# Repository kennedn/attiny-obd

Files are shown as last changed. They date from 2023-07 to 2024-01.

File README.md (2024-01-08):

# attiny-obd

Display OBD statistics on a 16x2 LCD display using an attiny85.

This project hijacks the tx and rx serial lines on a conventional ELM327 OBD interface device to send and retreive data. This data is then displayed in a nice format on an LCD1602 via i2c.

<p align="center">
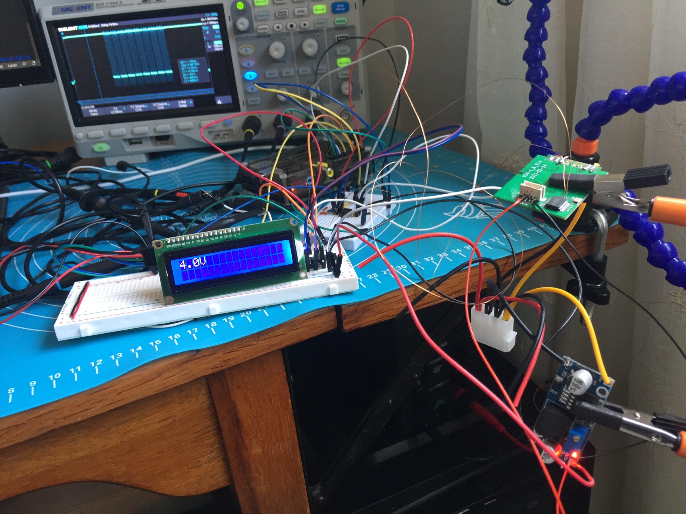
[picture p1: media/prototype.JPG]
    
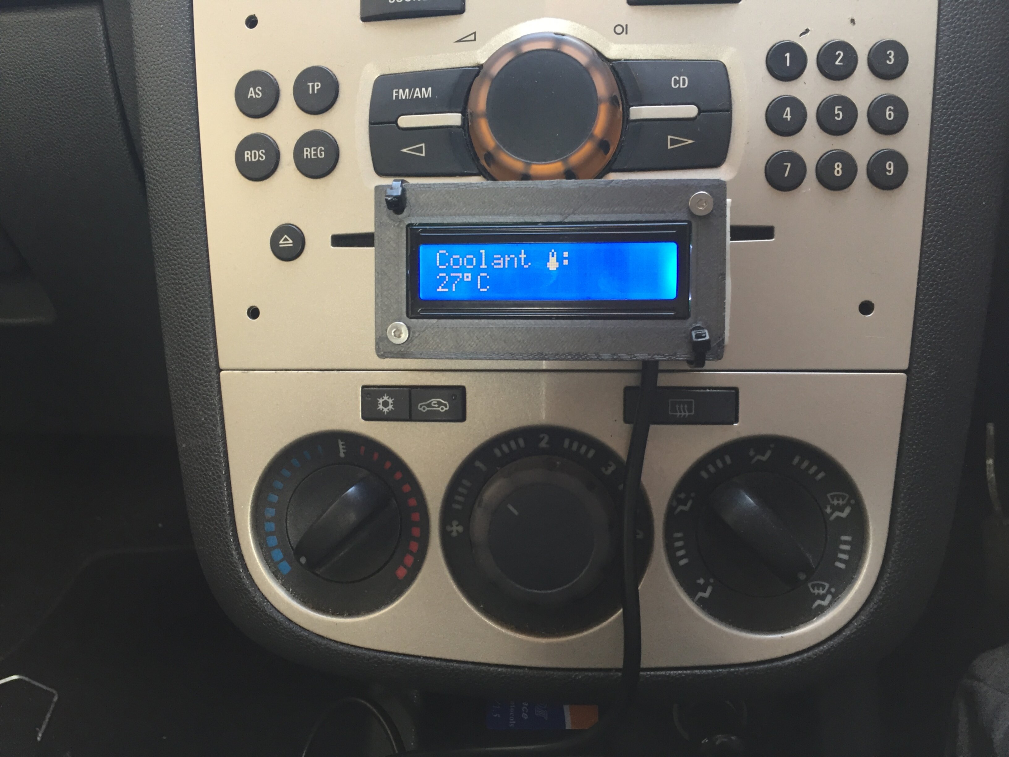
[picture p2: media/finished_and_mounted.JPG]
    
</p>
<p align="center">
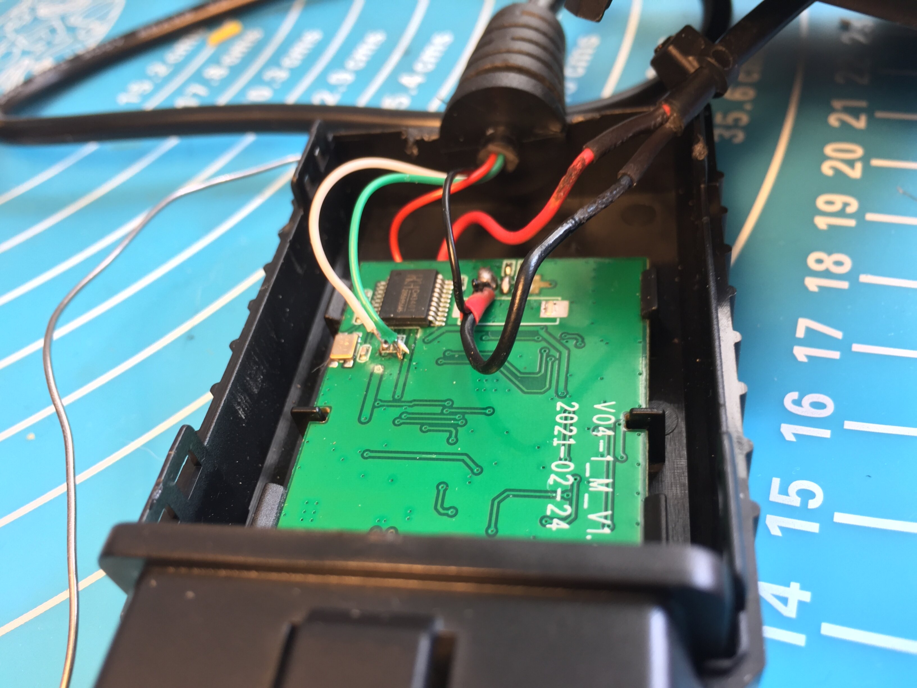
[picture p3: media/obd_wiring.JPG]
    
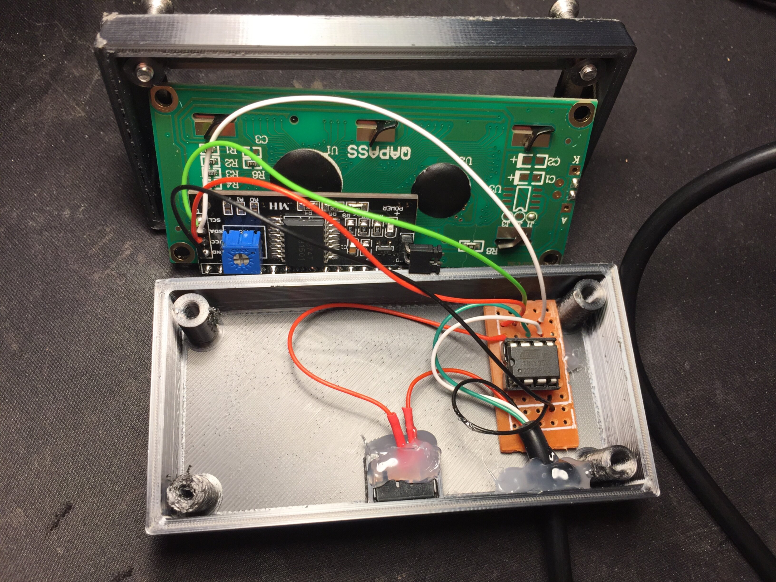
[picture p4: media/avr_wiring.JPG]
    
</p>

## Compiling and programming

An AVR programmer of choice can be used to program the attiny85, however a really easy way to achieve this is by using a spare raspberry pi as an SPI programmer. See the following blog post by Kevin Cuzner on how to set this up:

https://web.archive.org/web/20220629132626/http://kevincuzner.com/2013/05/27/raspberry-pi-as-an-avr-programmer/

Assuming that the linuxspi programmer is being used on a raspberry pi, the steps are:

### Configure the linuxspi programmer

The linuxspi programmer has a reset function that can drive the reset pin on the AVR device low to enable SPI programming. To enable this feature the following config should be placed at `/root/.avrduderc`:

```text
programmer
  id = "linuxspi";
  desc = "Use Linux SPI device in /dev/spidev*";
  type = "linuxspi";
  reset = 22;
;
```

### Connect Raspberry pi to attiny85

The following pinout should be followed:

| Rasp pi | attiny85 |
|---|---|
| GPIO 22 | PB5 |
| GPIO 10 | PB0 |  
| GPIO 09 | PB1 |  
| GPIO 11 | PB2 |  

### Configure the fuses on the device

The following changes need made to the stock fuse configuration for the attiny85 to run `avr-obd`:

- Clock divider bit CKDIV8 unset, this allows the attiny85 to run at 8Mhz
- Brown-out detection bits BODLEVEL[2:0] set to 4.3v, this prevents the 3.3v TX and RX lines of the ELM327 from  powering the device

The following `avrdude` command will set the correct bits on the fuses:

```bash
sudo avrdude -p t85 -P /dev/spidev0.0 -c linuxspi -b 30000 -U lfuse:w:0x62:m -U hfuse:w:0xdc:m -U efuse:w:0xff:m
```

Fuse values calculated using [Fuse Calculator](https://www.engbedded.com/fusecalc/).

### Run the Makefile

The makefile will build each *.c file under `src/` and then link them, it can also call avrdude to perform the spi copy.

```bash
cd src/avr-obd
make install
```

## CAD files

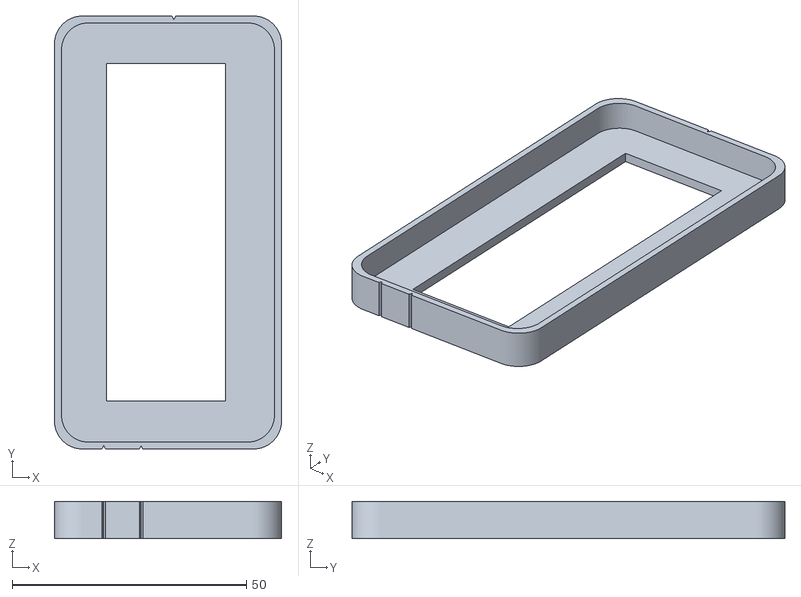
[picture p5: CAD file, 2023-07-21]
stl/lcd1602_lid.stl
48.5 x 92.5 x 8.00

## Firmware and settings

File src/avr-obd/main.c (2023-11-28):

#include <avr/io.h>
#include <util/delay.h>

#include "elm327.h"
#include "lcd1602.h"

#include <stdlib.h>
#define LEFT_PIN PB4
#define RIGHT_PIN PB3
#define DELAY_MS 500

unsigned int delay_ms = 0;

int main(void) {
    lcd_initialise();
    elm327_initalise();
    PORTB |= _BV(LEFT_PIN) | _BV(RIGHT_PIN); //enable pullup on input buttons

    while (1) {
       // Check for button press, debounce and break if detected
       while (delay_ms < DELAY_MS) {
            if (!(PINB & _BV(LEFT_PIN))) {  // Left button pressed
                elm327_previous_command();
                break;
            } else if (!(PINB & _BV(RIGHT_PIN))) {  // Right button pressed
                elm327_next_command();
                break;
            }
            delay_ms++;
            _delay_ms(1);
        }

        elm327_update_data();

        // Setup USI for TWI communication
        lcd_usi_initialise();

        lcd_move(0x00);
        lcd_print_cstring(elm327_get_prefix());
        lcd_print_long(elm327_get_data());
        lcd_print_cstring(elm327_get_suffix());
        lcd_print_padding(6);

        lcd_move(0x40);
        //lcd_print_cstring("Max: ");
        lcd_print_long(elm327_get_eeprom_data());
        lcd_print_cstring(elm327_get_suffix());
        lcd_print_padding(6);
   
        // Delay for any remaining time in the case that a button press broke the prior loop early 
        while (delay_ms < DELAY_MS) {
            delay_ms++;
           _delay_ms(1);
        }
        delay_ms = 0;
    }
    return 0;
}

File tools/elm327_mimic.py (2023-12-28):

#!/usr/bin/env python3

import serial
import logging
import random
from time import time
import argparse
import RPi.GPIO as GPIO

targets = []
byte_count = 1

logging.basicConfig(
        format='%(asctime)s.%(msecs)03d [%(targets)s %(targets_hex)s] %(message)s',
    level=logging.INFO,
    datefmt='%Y-%m-%d %H:%M:%S')

old_factory = logging.getLogRecordFactory()

def record_factory(*args, **kwargs):
    record = old_factory(*args, **kwargs)
    record.targets = ','.join([f'{targets[x]}' for x in range(byte_count)])
    record.targets_hex = ','.join([f'0x{targets[x]:02x}' for x in range(byte_count)])
    return record

logging.setLogRecordFactory(record_factory)

def move_data_towards_target(data, target):
    if data == target:
        target = random.randint(0,0xFF)

    elif data < target:
        data += 1
    else:
        data -= 1
    return data, target

def format_data(datas, bytes):
    s = ''
    for x in range(bytes):
        s += f'{datas[x]:02x} '
    return s

def main():
    parser = argparse.ArgumentParser(description="Simulate an ELM327 connected to a car")
    parser.add_argument("-p", "--port", default='/dev/ttyAMA0', help="Set serial port")
    parser.add_argument("-b", "--baudrate", type=int, default=38400, help="Set baudrate")
    parser.add_argument("-d", "--disconnected", action="store_true", help="Respond as if the car is disconnected")
    parser.add_argument("-i", "--initial_data", type=int, default=-1, help="Respond as if the car is disconnected")
    args = parser.parse_args()

    last_run_ms = 0
    curr_ms = 0
    wait_ms = 0

    max_data_bytes = 4
    extra_data_pids = {
        "0102": 2,
        "0110": 2,
    }

    global targets
    global byte_count
    datas = []
    for i in range(max_data_bytes):
        if args.initial_data != -1:
            datas.append(args.initial_data)
        else:
            datas.append(random.randint(0, 0xFF))
        targets.append(random.randint(0, 0xFF))

    with serial.Serial(args.port,args.baudrate) as ser:
        # Toggle RESET pin on attiny
        GPIO.setwarnings(False)
        GPIO.setmode(GPIO.BCM)
        GPIO.setup(22, GPIO.OUT)
        GPIO.output(22, GPIO.LOW)
        GPIO.output(22, GPIO.HIGH)
        while True:
            s = ''
            while True:
                    s += ser.read().decode()
                    if s[-1] == '\r': break

            logging.info("< {}".format(s.replace('\r','\\r')))
            command = b''
            curr_ms = time() * 1000
            # We can safely skip configuration commands in our sim (AT*)
            if s.startswith('AT'):
                command = b'>'
            else:
                byte_count = extra_data_pids.get(s[0:4], 1)
                # Pick a random amount of time to wait between data changes
                if curr_ms - last_run_ms >= wait_ms:
                    last_run_ms = time() * 1000
                    wait_ms = random.randint(100,3000)
                    for x in range(byte_count):
                        datas[x], targets[x] = move_data_towards_target(datas[x],targets[x])

                if args.disconnected:
                    command = 'NO DATA \r\r>'.encode()
                else: 
                    command = '7E8 03 4{:s} {:s} {:s}\r\r>'.format(s[1], s[2:4], format_data(datas, byte_count)).encode()

            logging.info("> {}".format(command.decode().replace('\r','\\r')))
            # Reply to device with command    
            ser.write(command)

if __name__ == "__main__":
    main()

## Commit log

2023-07-05 Add serial recording of newer elm327 device
2023-07-08 Initial serial implementation (broken)
    [main.c]
2023-07-16 Get elm327 communication working via USI UART
2023-07-16 Combine projects into working prototype.
    Following features have been integrated into a working prototype:
    - elm327 initialisation and communication
    - lcd1602 initalisation and character printing
    - No longer require 4066 analog switch. SCL can be tied low to prevent uart data from being clocked to lcd display
    [main.c]
2023-07-21 Productionised code and general cleanup
    - Load custom icon into lcd1602 CGRAM
    - Retrieve coolant temp from OBD device
    - Add error handling for "NO DATA" scenario
    - Add hex string to temperature conversion
    - Remove old code folders
    - Fix whitespace
    [lcd1602_lid.stl]
2023-11-26 Refactor ahead of multi-command and simulator
    - Refactor elm327 code to facilitate swap in of other commands
    - Create elm327 simulator in python that can reply to attiny85
    [elm327_mimic.py, main.c]
2023-11-27 Add multi commands and button control
2023-11-28 Take measures to reduce SRAM usage (was at 100%!)
    - Swap UART bit reverse lookup table with for loop
    - Begin refactor of elm327 to use progmem for long strings
    - Begin refactor of lcd1602 to use progmem for long strings
    - Add size target in Makefile to show SRAM usage of compiled code
    [main.c]
2023-12-10 Standardise storage slots in EEPROM
2023-12-28 Add error detection and improve simulation
    [elm327_mimic.py]
2023-12-28 Preserve PID display in NO DATA case
